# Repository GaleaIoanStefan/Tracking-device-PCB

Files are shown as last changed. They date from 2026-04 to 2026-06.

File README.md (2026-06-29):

# Project description

In this project i have designed and coded a shield for the STM32 Nucleo board L476RG.

The shield is the prototype of a tracker that will update the position using a GPS module and a LoRa modem for communication with a server.
The board is made to connect to the Orange LiveObjects server from which the data is put inside a MongoDB database and later a template is made in Grafana with the longitude and latitude coordinates.
Two Python scripts are present in the project. One for getting the data from the LiveObjects through MQTT protocol, and the other links the data received to a endpoint. That endpoint in later linked to a Grafana JSON plugin to gather that data.

The programming of the board was done in STM32CubeIDE and all communications between The GPS, Lora and COM port were UART communications.

# The Electrical Schematic



# The layout of the PCB



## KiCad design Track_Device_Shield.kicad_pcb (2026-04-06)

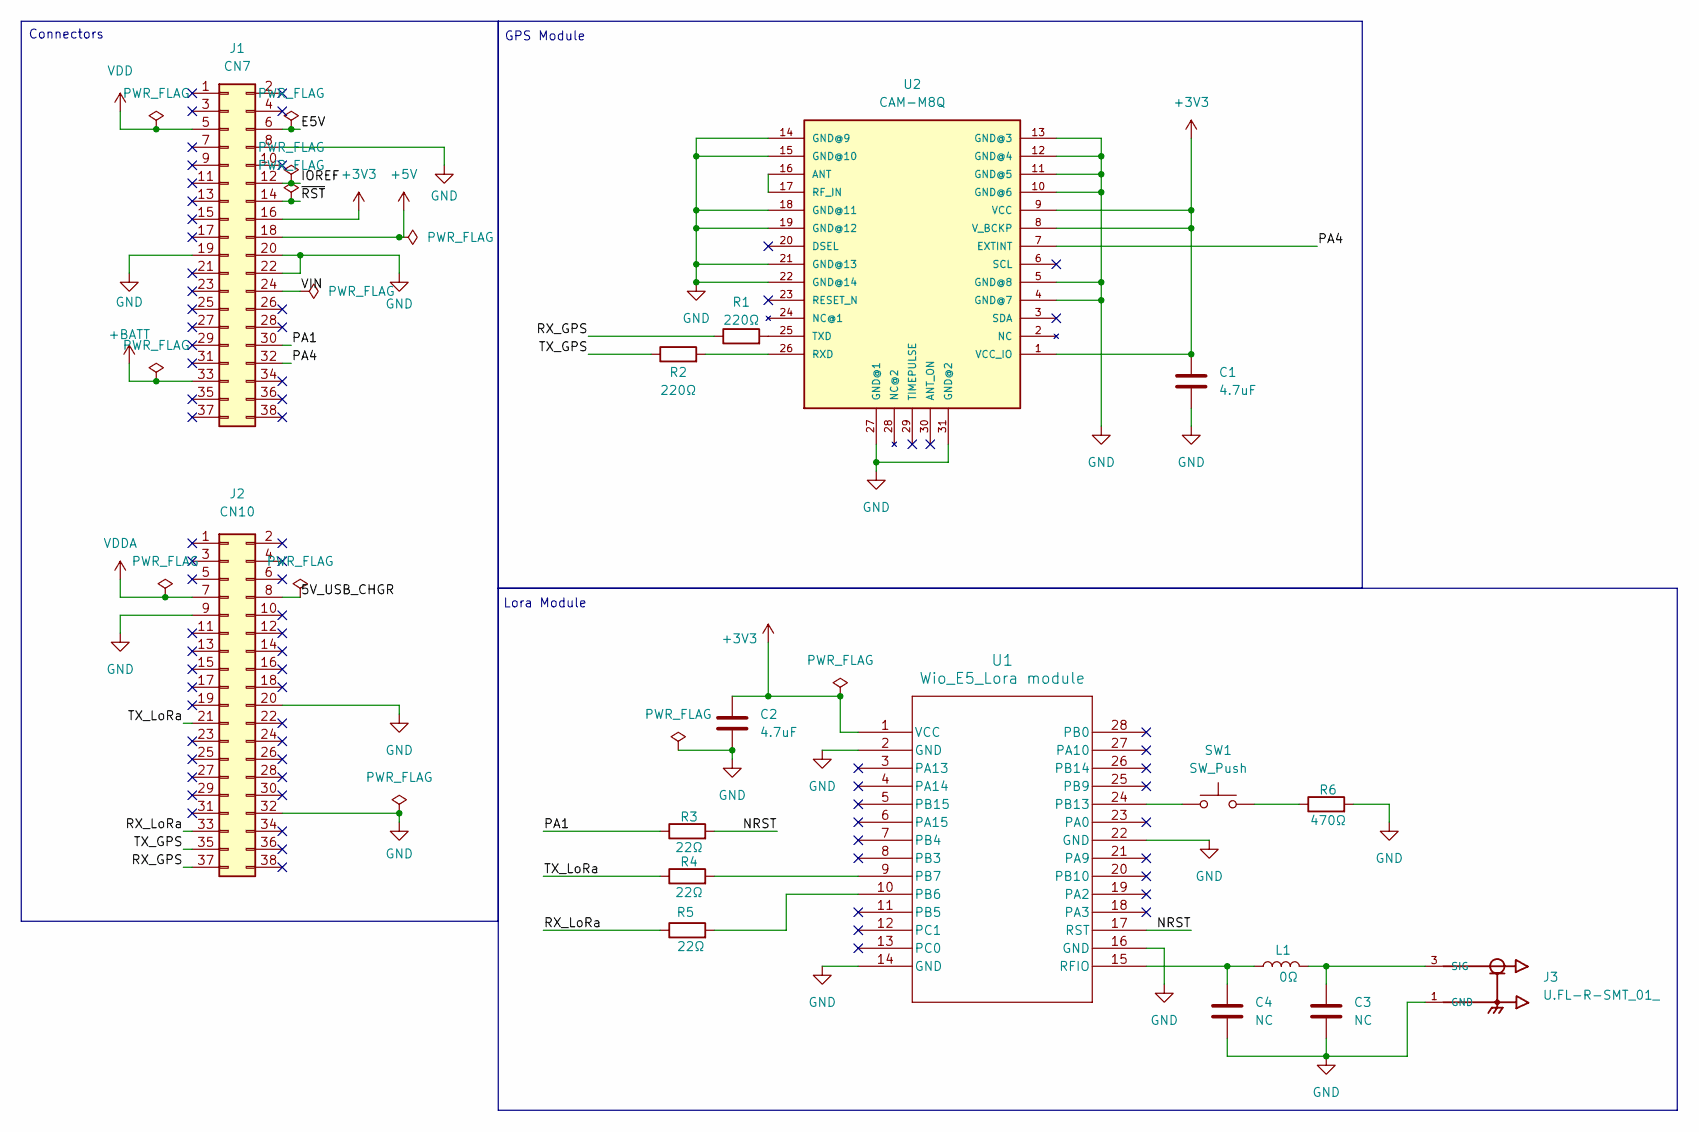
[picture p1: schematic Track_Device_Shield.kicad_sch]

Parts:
C1: 4.7uF; C_0805_2012Metric_Pad1.18x1.45mm_HandSolder
C2: 4.7uF; C_0805_2012Metric
C3, C4: NC; C_0805_2012Metric
J1: CN7; PinSocket_2x19_P2.54mm_Vertical
J2: CN10; PinSocket_2x19_P2.54mm_Vertical
J3: U.FL-R-SMT_01_; HRS_U.FL-R-SMT_01_
L1: 0Ω; L_0603_1608Metric
R1, R2: 220Ω; R_0603_1608Metric_Pad0.98x0.95mm_HandSolder
R3, R4, R5: 22Ω; R_0402_1005Metric
R6: 470Ω; R_0402_1005Metric
SW1: SW_Push; SW_PUSH_6mm
U1: Wio_E5_Lora module; Wio_E5_Lora module footprint
U2: CAM-M8Q; CAM-M8

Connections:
+3V3: C1.1, C2.1, J1.16, U1.1 (VCC), U2.1 (VCC_IO), U2.8 (V_BCKP), U2.9 (VCC)
+5V: J1.18
+BATT: J1.33
/5V_USB_CHGR: J2.8
/E5V: J1.6
/IOREF: J1.12
/NRST: R3.2, U1.17 (RST)
/PA1: J1.30, R3.1
/PA4: J1.32, U2.7 (EXTINT)
/RX_GPS: J2.37, R1.1
/RX_LoRa: J2.33, R5.1
/TX_GPS: J2.35, R2.1
/TX_LoRa: J2.21, R4.1
/VIN: J1.24
/~RST: J1.14
GND: C1.2, C2.2, C3.2, C4.2, J1.8, J1.19, J1.20, J1.22, J2.9, J2.20, J2.32, J3.1 (GND), J3.2 (GND), R6.2, U1.2 (GND), U1.14 (GND), U1.16 (GND), U1.22 (GND), U2.4 (GND@7), U2.5 (GND@8), U2.10 (GND@6), U2.11 (GND@5), U2.12 (GND@4), U2.13 (GND@3), U2.14 (GND@9), U2.15 (GND@10), U2.18 (GND@11), U2.19 (GND@12), U2.21 (GND@13), U2.22 (GND@14), U2.27 (GND@1), U2.31 (GND@2)
unnamed: C3.1, J3.3 (SIG), L1.2
unnamed: R6.1, SW1.2
unnamed: R5.2, U1.10 (PB6)
unnamed: R4.2, U1.9 (PB7)
unnamed: SW1.1, U1.24 (PB13)
unnamed: C4.1, L1.1, U1.15 (RFIO)
unnamed: U2.16 (ANT), U2.17 (RF_IN)
unnamed: R2.2, U2.26 (RXD)
unnamed: R1.2, U2.25 (TXD)
VDD: J1.5
VDDA: J2.7

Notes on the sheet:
Lora Module
GPS Module
Connectors

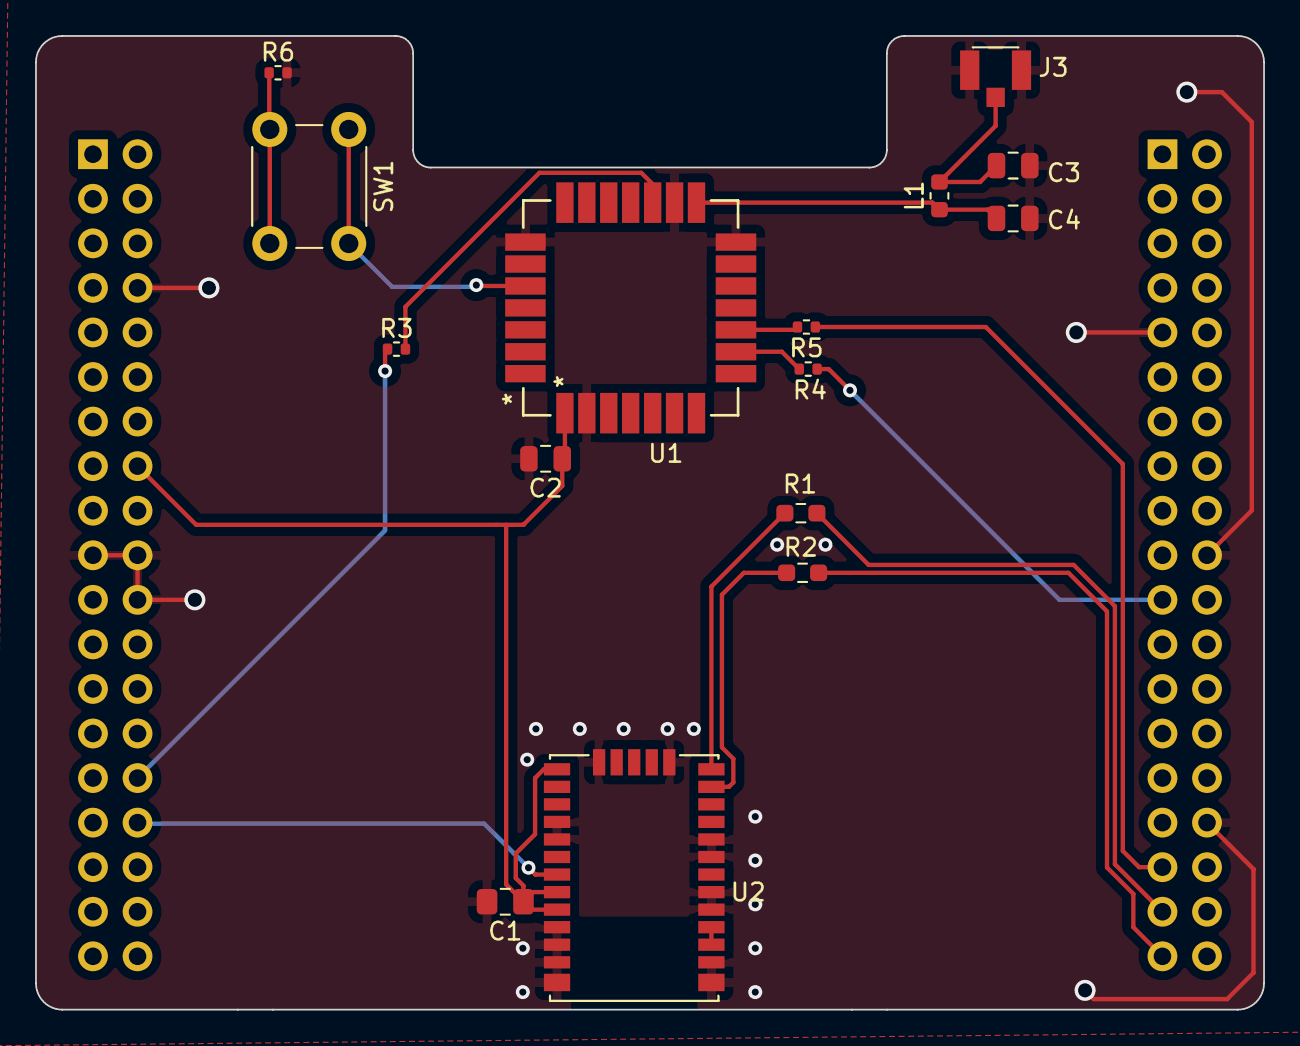
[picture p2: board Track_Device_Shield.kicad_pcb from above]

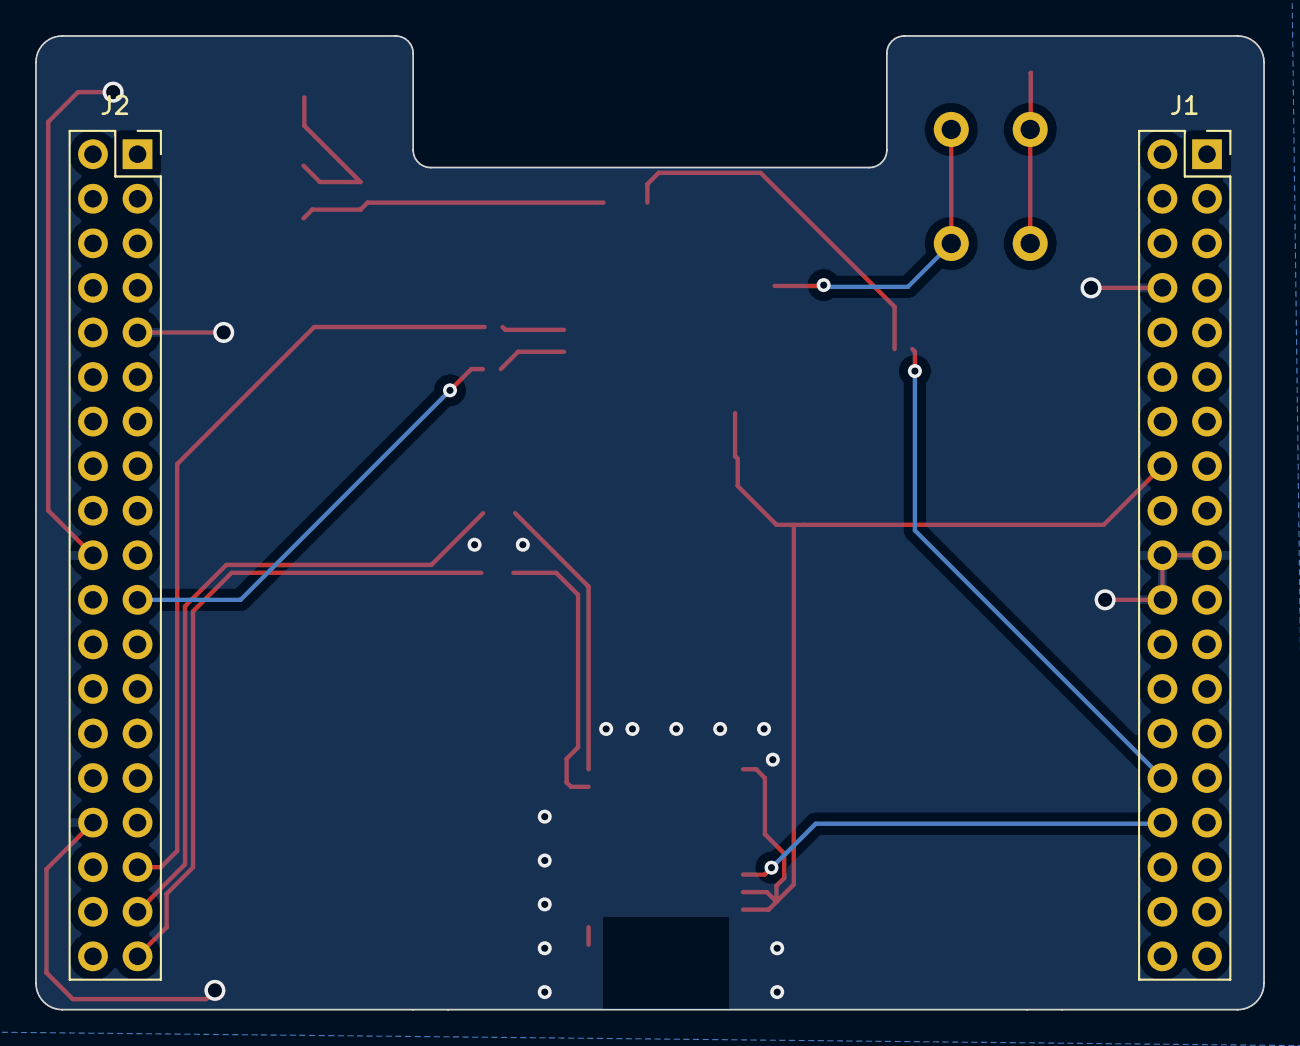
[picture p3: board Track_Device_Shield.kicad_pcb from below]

Board: 2 copper layers, 70.0 x 55.5 mm, 17 parts (2 on the bottom side), 18 nets.

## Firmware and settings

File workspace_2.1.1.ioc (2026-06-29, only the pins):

Mcu.UserName=STM32L476RGTx
PA10.Signal=USART1_RX
PA2.Signal=USART2_TX
PA3.GPIO_Label=USART_RX
PA3.Signal=USART2_RX
PA5.GPIO_Label=LD2 [green Led]
PA5.Signal=GPIO_Output
PA9.Signal=USART1_TX
PC10.Signal=USART3_TX
PC11.Signal=USART3_RX
PC13.GPIO_Label=B1 [Blue PushButton]
PC13.Signal=GPXTI13
